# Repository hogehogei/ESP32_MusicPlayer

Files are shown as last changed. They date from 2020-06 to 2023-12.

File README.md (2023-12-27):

# ESP32 MusicPlayer sample

## 概要
- Bluetooth Classic 接続 / SDカードから　音声再生可能なミュージックプレーヤ
- 音声再生機能は VS1053b に丸投げ

## ビルド方法
ESP-IDF v4.4 にてビルド確認。 esp32 wroom 32 (無印esp32) での設定。<br>
以下menuconfig設定要
- Compiler options -> Optimization Level (-O2)
- Component config -> Bluetooth ->
    - Bluetooth controller -> Bluetooth controller mode (BR/EDR Only)
    - Bluetooth Host -> (Bluedroid - Dual-mode)
    - Bluedroid Options ->
        - [*] Classic Bluetooth
        - [*] A2DP
        - [*] SPP
- Component config -> ESP System Settings ->  Panic handler behaviour (Print registers and halt)
- Serial flasher config -> Flash size (4MB)
- Partition Table -> PartitionTable (custom partition table CSV)

最適化有効にしないとBluetoothパケットドロップするので最適化必須、CPUクロックは160MHzで動作。<br>
パーティションは partition.csv を参照する。

ビルドコマンド<br>
```
$ cd main
$ idf.py build
```

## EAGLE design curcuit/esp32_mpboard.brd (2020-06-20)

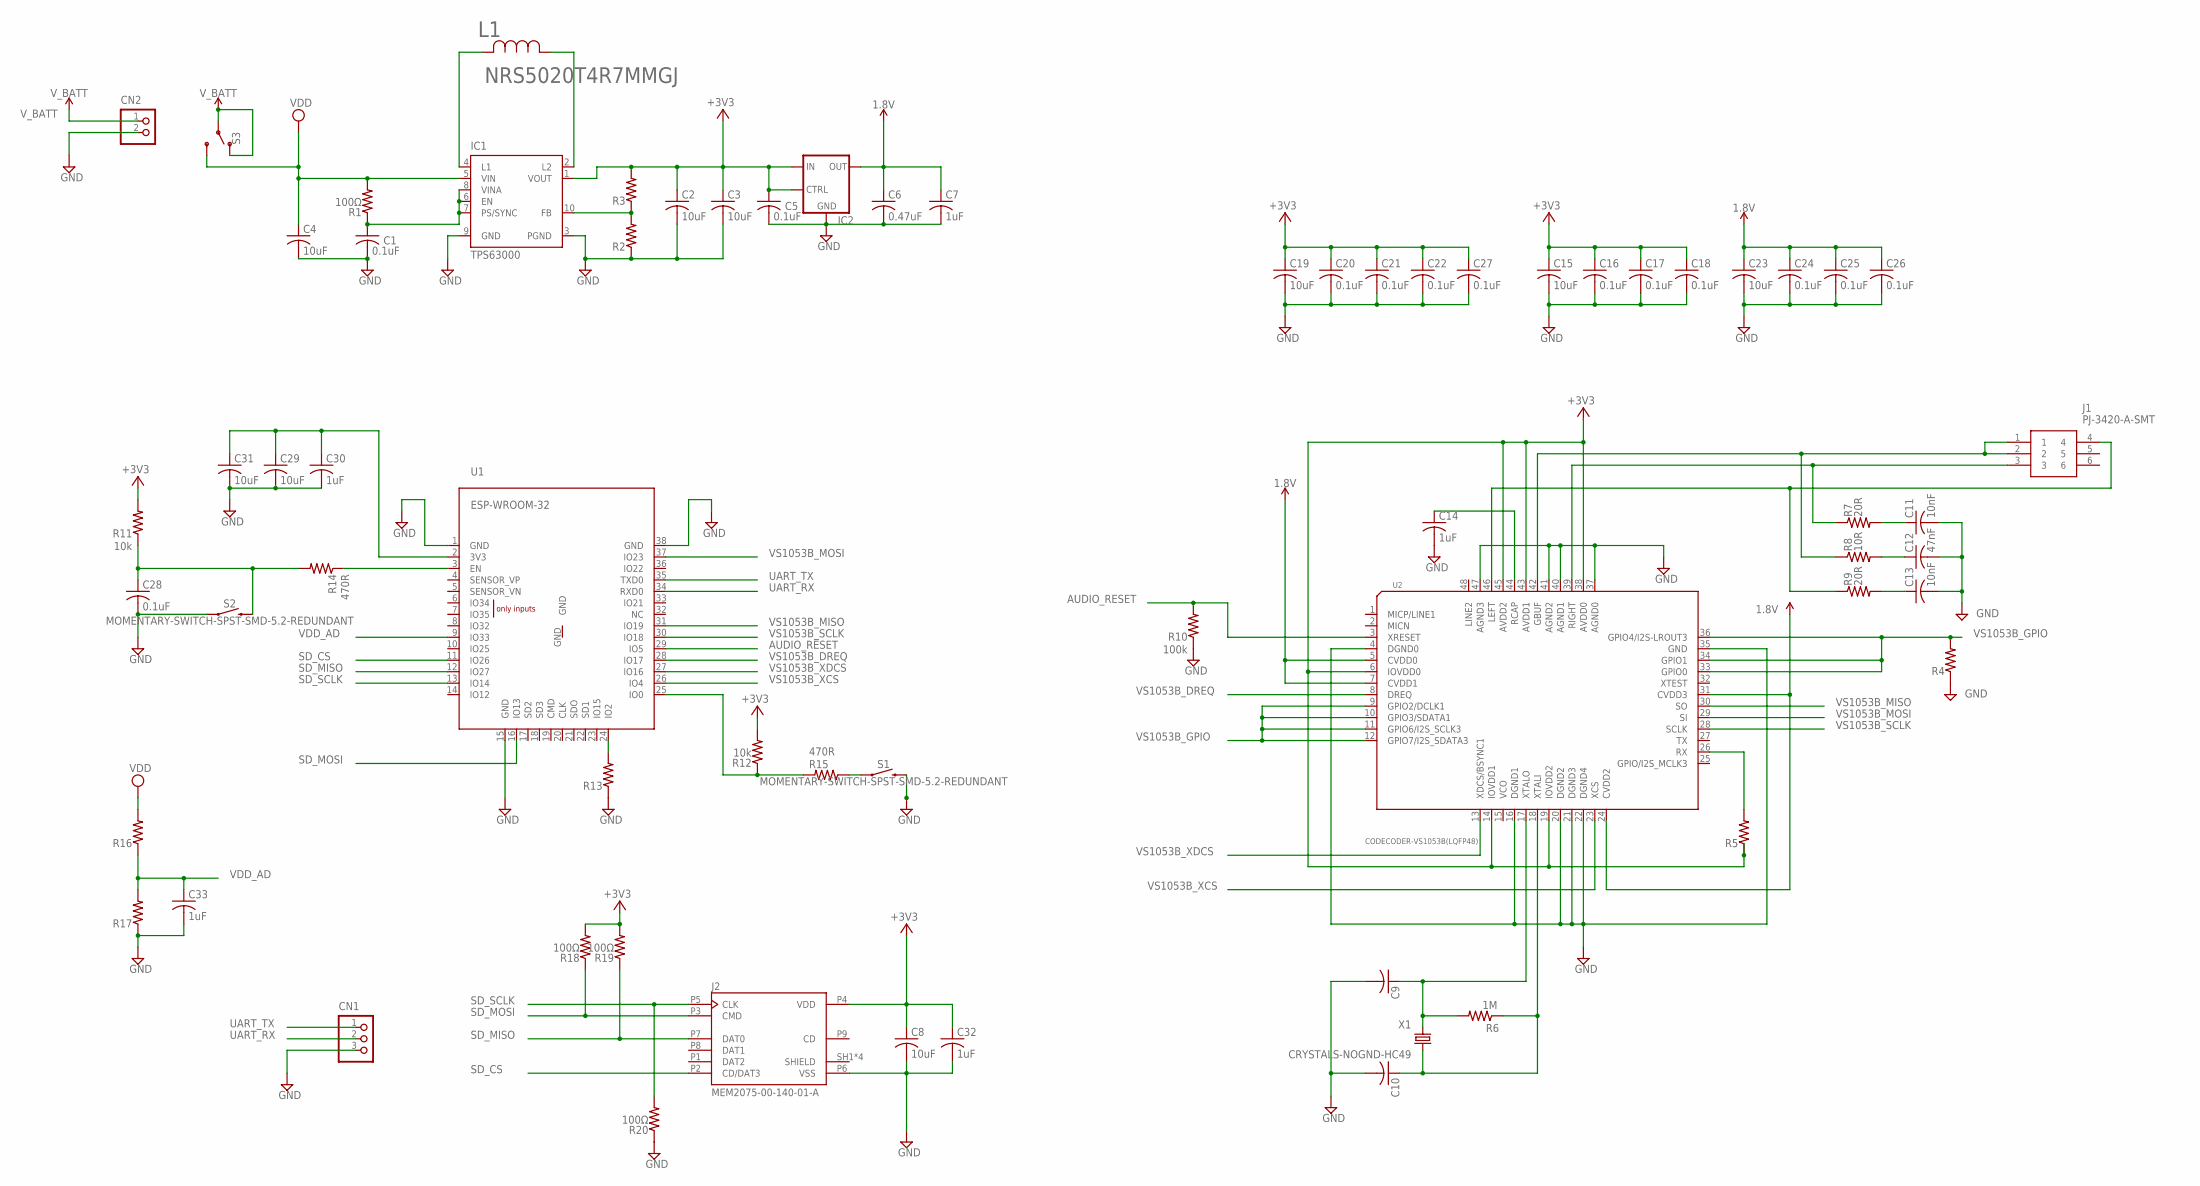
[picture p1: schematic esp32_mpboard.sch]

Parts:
C1, C5, C16, C17, C18, C20, C21, C22, C24, C25, C26, C27, C28: 0.1uF; C0603
C2, C3, C4, C8, C15, C19, C23, C29, C31: 10uF; C0805
C6: 0.47uF; C0603
C7, C14, C30, C32, C33: 1uF; C0603
C9, C10: C-USC0603; C0603
C11, C13: 10nF; C0603
C12: 47nF; C0603
CN1: B3B-XH-A
CN2: B2B-XH-A
IC1: TPS63000; DRC-S-PVSON-N10_MANUALSOLDER
IC2: NJM12888F1812DBV; SOT23-5
J1: PJ-3420-A-SMT; PJ3420ASMT
J2: MEM2075-00-140-01-A; GCT_MEM2075-00-140-01-A
L1: NRS5020T4R7MMGJ; IND_TAIYO_NRS5020
R1, R18, R19, R20: 100Ω; R0603
R2, R3, R4, R5, R13, R16, R17: R-US_R0603; R0603
R6: 1M; R0603
R7, R9: 20R; R0603
R8: 10R; R0603
R10: 100k; R0603
R11, R12: 10k; R0603
R14, R15: 470R; R0603
S1, S2: MOMENTARY-SWITCH-SPST-SMD-5.2-REDUNDANT; TACTILE_SWITCH_SMD_5.2MM
S3: SWITCH-SPDT-PTH-11.6X4.0MM; SWITCH_SPDT_PTH_11.6X4.0MM
U1: ESP-WROOM-32
U2: CODECODER-VS1053B(LQFP48); LQFP48-0.5-7X7MM
X1: CRYSTALS-NOGND-HC49; HC49

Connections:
1.8V: C6.1, C7.1, C23.1, C24.1, C25.1, C26.1, IC2.5 (OUT), U2.5 (CVDD0), U2.7 (CVDD1), U2.24 (CVDD2), U2.31 (CVDD3)
1.8V1: C9.1, R6.2, U2.17 (XTALO), X1.2
3V3: C2.1, C3.1, C5.1, C8.1, C15.1, C16.1, C17.1, C18.1, C19.1, C20.1, C21.1, C22.1, C27.1, C29.1, C30.1, C31.1, C32.1, IC1.1 (VOUT), IC2.1 (IN), IC2.3 (CONTROL), J2.P4 (VDD), R3.2, R5.1, R5.2, R12.2, R18.2, R19.2, U1.2 (3V3), U2.6 (IOVDD0), U2.14 (IOVDD1), U2.19 (IOVDD2), U2.26 (RX), U2.38 (AVDD0), U2.43 (AVDD1), U2.45 (AVDD2)
+3V3: R11.2
AUDIO_RESET: R10.2, U1.29 (IO5), U2.3 (XRESET)
GND: C1.2, C2.2, C3.2, C4.2, C5.2, C6.2, C7.2, C8.2, C9.2, C10.2, C11.2, C12.2, C13.2, C14.2, C15.2, C16.2, C17.2, C18.2, C19.2, C20.2, C21.2, C22.2, C23.2, C24.2, C25.2, C26.2, C27.2, C28.2, C29.2, C30.2, C31.2, C32.2, C33.2, CN1.3, CN2.2, IC1.3 (PGND), IC1.9 (GND), IC2.2 (GND), J2.P6 (VSS), R2.1, R4.1, R10.1, R13.1, R17.1, R20.1, S1.3 (2), S1.4 (2), S2.1, S2.2 (1), U1.1 (GND), U1.15 (GND), U1.38 (GND), U2.4 (DGND0), U2.16 (DGND1), U2.20 (DGND2), U2.21 (DGND3), U2.22 (DGND4), U2.35 (GND), U2.37 (AGND0), U2.40 (AGND1), U2.41 (AGND2), U2.47 (AGND3)
GND1: C10.1, R6.1, U2.18 (XTALI), X1.1
unnamed: IC1.4 (L1), L1.2
unnamed: IC1.2 (L2), L1.1
unnamed: C1.1, IC1.6 (EN), IC1.7 (PS/SYNC), IC1.8 (VINA), R1.1
unnamed: IC1.10 (FB), R2.2, R3.1
unnamed: J1.4, R9.1, U2.46 (LEFT)
unnamed: J1.1, J1.2, R8.1, U2.42 (GBUF)
unnamed: J1.3, R7.1, U2.39 (RIGHT)
unnamed: C12.1, R8.2
unnamed: C13.1, R9.2
unnamed: C11.1, R7.2
unnamed: R12.1, R15.2, U1.25 (IO0)
unnamed: C14.1, U2.44 (RCAP)
unnamed: C28.1, R11.1, R14.2, S2.3 (2), S2.4 (2)
unnamed: R13.2, U1.24 (IO2)
unnamed: R14.1, U1.3 (EN)
unnamed: R15.1, S1.1, S1.2 (1)
SD_CS: J2.P2 (CD/DAT3), U1.11 (IO26)
SD_MISO: J2.P7 (DAT0), R19.1, U1.12 (IO27)
SD_MOSI: J2.P3 (CMD), R18.1, U1.16 (IO13)
SD_SCLK: J2.P5 (CLK), R20.2, U1.13 (IO14)
SHIELD: J2.SH1 (SHIELD), J2.SH2 (SHIELD), J2.SH3 (SHIELD), J2.SH4 (SHIELD)
UART_RX: CN1.2, U1.34 (RXD0)
UART_TX: CN1.1, U1.35 (TXD0)
VCO: U2.15 (VCO)
VDD: C4.1, IC1.5 (VIN), R1.2, R16.2, S3.3 (S)
VDD_AD: C33.1, R16.1, R17.2, U1.9 (IO33)
VS1053B_DREQ: U1.28 (IO17), U2.8 (DREQ)
VS1053B_GPIO: R4.2, U2.9 (GPIO2/DCLK1), U2.10 (GPIO3/SDATA1), U2.11 (GPIO6/I2S_SCLK3), U2.12 (GPIO7/I2S_SDATA3), U2.33 (GPIO0), U2.34 (GPIO1), U2.36 (GPIO4/I2S-LROUT3)
VS1053B_MISO: U1.31 (IO19), U2.30 (SO)
VS1053B_MOSI: U1.37 (IO23), U2.29 (SI)
VS1053B_SCLK: U1.30 (IO18), U2.28 (SCLK)
VS1053B_XCS: U1.26 (IO4), U2.23 (XCS)
VS1053B_XDCS: U1.27 (IO16), U2.13 (XDCS/BSYNC1)
V_BATT: CN2.1, S3.1 (O), S3.2

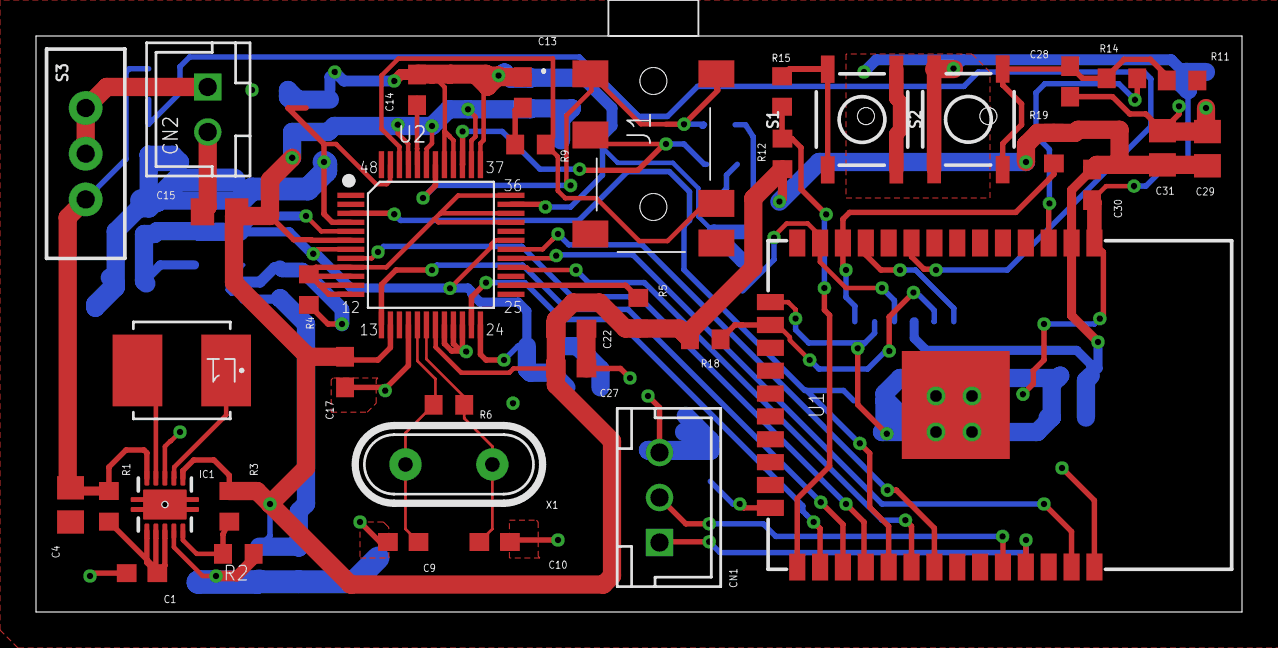
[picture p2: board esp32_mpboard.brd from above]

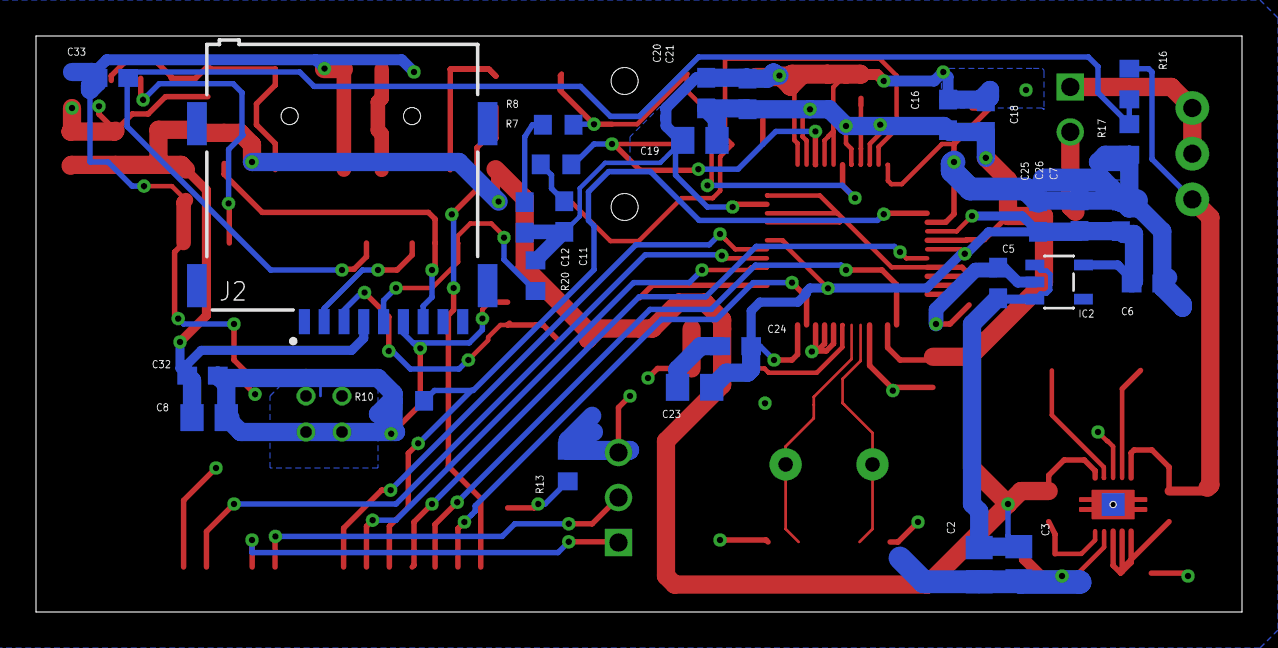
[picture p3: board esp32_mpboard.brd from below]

Board: 2 copper layers, 67.0 x 32.0 mm, 66 parts (28 on the bottom side), 39 nets.

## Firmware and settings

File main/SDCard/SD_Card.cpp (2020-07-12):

#include "SD_Card.hpp"

#include <limits>
#include <algorithm>

// esp-idf headers
#include "esp_log.h"

// FreeRTOS headers
#include <freertos/FreeRTOS.h>
#include <freertos/task.h>

// SDCard Command Set
static constexpr uint8_t sk_CMD0        = (0x40 + 0);
static constexpr uint8_t sk_CMD1        = (0x40 + 1);
static constexpr uint8_t sk_CMD8        = (0x40 + 8);
static constexpr uint8_t sk_CMD9        = (0x40 + 9);
static constexpr uint8_t sk_CMD16       = (0x40 + 16);
static constexpr uint8_t sk_CMD17       = (0x40 + 17);
static constexpr uint8_t sk_CMD25       = (0x40 + 25);
static constexpr uint8_t sk_ACMD41      = (0xC0 + 41);
static constexpr uint8_t sk_CMD55       = (0x40 + 55);
static constexpr uint8_t sk_CMD58       = (0x40 + 58);
static constexpr uint8_t sk_ACMD_Mask   = (0x80);                   //! ACMDマスク値 コマンドにANDして1の場合はACMD
static constexpr uint32_t sk_ACMD41_HCS = (1UL << 30);
static constexpr uint32_t sk_ACMD58_CCS = (0x40);

// SDCard Command Response
static constexpr uint8_t sk_CMD_RES_InIdleState = (1 << 0);
static constexpr uint8_t sk_CMD_RES_OK  = 0x00;

// SDCard Data Token
static constexpr uint8_t sk_ErrorTokenMask     = 0x01;              //! エラートークンマスク
static constexpr uint8_t sk_DataToken_Read     = 0xFE;              //! CMD17 データトークン
static constexpr uint8_t sk_DataToken_CMD25    = 0xFC;              //! CMD25 データトークン
static constexpr uint8_t sk_StopTransToken_CMD25 = 0xFD;            //! CMD25 StopTrans

// SDCard Data Response
static constexpr uint8_t sk_DATA_RES_OK_Mask = 0x1F;
static constexpr uint8_t sk_DATA_RES_OK      = 0x05;

// SDCard Type
static constexpr uint8_t sk_SDC_Type_None   = 0;                    //! SDカードタイプ無し。初期化に失敗した時とかはこれ
static constexpr uint8_t sk_SDC_Type_SD1    = (1 << 0);             //! SDカード = SDv1
static constexpr uint8_t sk_SDC_Type_SD2    = (1 << 1);             //! SDカード = SDv2
static constexpr uint8_t sk_SDC_Type_MMC    = (1 << 2);             //! SDカード = MMC
static constexpr uint8_t sk_SDC_Block       = (1 << 3);             //! ブロックアクセス     1の場合はコマンドのアドレス指定はsector単位を用いる。
                                                                    //!                     0の場合はコマンドのアドレス指定はbyte単位。

// read() / write() 関数の引数 sector を byte に変換するときに
// sector がとりうることのできる最大値
static constexpr uint32_t k_MaxSector_ByteAccess = (std::numeric_limits<uint32_t>::max() / SD_Card::sk_SectorSize);

// SDカードアクセス時間指定

static constexpr uint8_t sk_SDC_InitDelay_ms    = 100;              //! SDC初期化ウェイト[ms]
static constexpr int sk_SDC_InitSCLK            = 10;               //! SDC初期化カウント[x8 clock]
static constexpr uint16_t sk_SDC_TimeOut_ms     = 1000;             //! SDCコマンドタイムアウト[ms]

static constexpr int sk_CMD_RespRetry           = 8192;             //! コマンドレスポンス読み出しリトライ回数
static constexpr int sk_DataPktReadWait         = 8192;             //! データパケットトークン読み出しリトライ回数
static constexpr int sk_WriteBusyCheckRetry     = 8192;             //! 書き込みビジーチェックリトライ回数

void showResp( const uint8_t resp );

SD_Card::Progress::Progress()
 :  addr( 0 ),
    remain_offset( 0 ),
    remain_sector( 0 ),
    remain_bytes_cursec( 0 ),
    remain_len( 0 )
{}

SD_Card::SD_Card()
 : m_SDC_Drv( nullptr ),
   m_W_Progress(),
   m_SDC_State( false ),
   m_IsWriteOpeProcessing( false ),
   m_CardType( 0 ),
   m_SectorCount( 0 )
{}

SD_Card::~SD_Card()
{}


bool SD_Card::Initialize( I_SDC_Drv_SPI* driver )
{
    // 初期化済み、かつ正常動作中なら何もしない。
    if( m_SDC_State == true ){
        return true;
    }

    // ドライバインターフェースを設定
    if( !driver ){
        m_SDC_State = false;
        return false;
    }
    m_SDC_Drv = driver;

    // SDカードドライバ初期化
    m_SDC_Drv->Initialize( sk_ClockSpeedHz_Initializing );
    sendInitializeClock();              // 初期化クロック送信
    m_CardType = initialize_Card();     // カード初期化
    // SPIの速度再設定
    m_SDC_Drv->Initialize( sk_ClockSpeedHz_AccessSD );
    
    if( m_CardType == sk_SDC_Type_None ){
        m_SDC_State = false;
    }
    else {
        // セクタサイズ読み込み
        readSectorSize();
        m_SDC_State = true;
    }

    // 初期化終了
    m_SDC_Drv->Release();

    printSDCardInfo();

    return m_SDC_State;
}

bool SD_Card::Read( uint8_t* dst, uint32_t sector, uint32_t offset, uint32_t len )
{
	// SDカード状態が不正ならエラー
	if( m_SDC_State == false ){
		return false;
	}

    if( len == 0 ){
        return true;
    }
    // 引数チェック
    // offset がセクタサイズ以上、もしくは
    // (offset + len) が32bitの取りえる値を超えていたら失敗
    if( dst == nullptr ||
        offset >= sk_SectorSize || 
        ((std::numeric_limits<uint32_t>::max() - offset) < len) ){
        return false;
    }
    // アクセス単位がbyte単位の場合に、上限値を超えたらエラー
    if( !(m_CardType & sk_SDC_Block) &&
        (sector > k_MaxSector_ByteAccess) ){
        return false;
    }

    // 進捗管理構造体
    Progress progress;
    bool result = readInitiate( &progress, sector, offset, len );

    // 3つの場合に分けて考える
    // step1: offset だけ先頭データを読み飛ばす
    // step2: 必要なデータをコピーする
    // step3: 必要なデータをすべて読み終わった後、最終セクタの余ったデータを読み飛ばす
    while( result &&
         (( progress.remain_len > 0 ) || ( progress.remain_bytes_cursec > 0 )) ){
#if 0
    	UART_Print( "Remain offset");
    	UART_HexPrint( (uint8_t* )&progress.remain_offset, 4 );
    	UART_Print( "Remain cursec");
    	UART_HexPrint( (uint8_t*)&progress.remain_bytes_cursec, 4 );
    	UART_Print( "Remain len");
    	UART_HexPrint( (uint8_t*)&progress.remain_len, 4 );
    	UART_Print( "Remain Sector");
    	UART_HexPrint( (uint8_t*)&progress.remain_sector, 4 );
#endif

        if( progress.remain_offset > 0 ){
            // step1
            ignoreRead( offset );
            progress.remain_bytes_cursec -= offset;
            progress.remain_offset = 0;
        }
        else if( progress.remain_len > 0 ){
            // step2
            uint32_t size = std::min( progress.remain_len, progress.remain_bytes_cursec );
            result = m_SDC_Drv->recv( dst, size );
            dst += size;
            progress.remain_len -= size;
            progress.remain_bytes_cursec -= size;
        }
        else if( progress.remain_bytes_cursec > 0 ){
            // step3 
            ignoreRead( progress.remain_bytes_cursec );
            progress.remain_bytes_cursec = 0;
        }
        else {
            result = false;
        }

        if( progress.remain_bytes_cursec == 0 ){
            // CRCを読み飛ばす
            ignoreRead( 2 );
            // 残りのセクタを読む必要があるなら次のセクタを読む
            if( progress.remain_sector > 0 ){
                if( !nextSectorReadPreparation( &progress ) ){
                    result = false;
                    break;
                }
            }
        }
    }

    m_SDC_Drv->Release();
    m_SDC_State = result;

    return result;
}
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

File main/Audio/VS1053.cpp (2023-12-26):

#include "VS1053.hpp"

#include <cstdint>
#include <cstring>
#include "Timer.hpp"

// esp headers
#include "esp_log.h"

#include <esp32/rom/ets_sys.h>

static constexpr uint32_t sk_SPI_Send_Timeout = 1000;
static constexpr uint32_t sk_SPI_Recv_Timeout = 1000;
static constexpr uint32_t sk_Busy_Timeout = 1000;

VS1053_Drv_SPI VS1053_Drv_SPI::s_Driver;

VS1053_Drv_SPI::VS1053_Drv_SPI()
    : m_IsInitialized( false )
{}

VS1053_Drv_SPI::~VS1053_Drv_SPI()
{}

VS1053_Drv_SPI& VS1053_Drv_SPI::Instance()
{
    return s_Driver;
}

void VS1053_Drv_SPI::Initialize( uint32_t spi_freq )
{
    // SPI 初期化
    initialize_SPI( spi_freq );
    // CS pin 初期化
    initialize_CS( sk_CmdCS_IONum );
    CommandRelease();
	initialize_CS( sk_DataCS_IONum );
    DataRelease();
    // DREQ pin 初期化
    initialize_DReq( sk_DReq_IONum );
    // Audio Reset pin 初期化
    initialize_AudioReset( sk_AudioReset_IONum );

    m_IsInitialized = true;
}

void VS1053_Drv_SPI::ResetSPI( uint32_t spi_freq )
{
    initialize_SPI( spi_freq );
}

bool VS1053_Drv_SPI::CommandSelect()
{
    gpio_set_level( sk_CmdCS_IONum, 0 );
    return true;
}

void VS1053_Drv_SPI::CommandRelease()
{
    gpio_set_level( sk_CmdCS_IONum, 1 );
}

bool VS1053_Drv_SPI::DataSelect()
{
    gpio_set_level( sk_DataCS_IONum, 0 );
    return true;
}

void VS1053_Drv_SPI::DataRelease()
{
    gpio_set_level( sk_DataCS_IONum, 1 );
}

void VS1053_Drv_SPI::AssertReset()
{
    gpio_set_level( sk_AudioReset_IONum, 0 );
}

void VS1053_Drv_SPI::DeassertReset()
{
    gpio_set_level( sk_AudioReset_IONum, 1 );
}

bool VS1053_Drv_SPI::IsBusy() const
{
    return gpio_get_level( sk_DReq_IONum ) == 0;
}

bool VS1053_Drv_SPI::Send( const uint8_t* data, uint16_t len )
{
	static spi_transaction_t trans;
	esp_err_t ret;

	if( data == nullptr ){
		return false;
	}
	
	memset( &trans, 0, sizeof(spi_transaction_t) );
	trans.length    = len * 8;          // bit で指定
	trans.tx_buffer = data;				
	ret = spi_device_transmit( m_SPIHandle, &trans );

	return ret == ESP_OK;
}

bool VS1053_Drv_SPI::Recv( uint8_t* data, uint16_t len )
{
	static spi_transaction_t trans;

	if( data == nullptr ){
		return false;
	}

	// 受信時も 0xFF を送信するようにする。
	constexpr int k_TxBufSize = 16;
	uint8_t txbuf[k_TxBufSize] = {0xFF, 0xFF, 0xFF, 0xFF, 0xFF, 0xFF, 0xFF, 0xFF,
								  0xFF, 0xFF, 0xFF, 0xFF, 0xFF, 0xFF, 0xFF, 0xFF };
	uint32_t remain_len = len;
	uint8_t* dstp = data;

	memset( &trans, 0, sizeof(spi_transaction_t) );

	while( remain_len >= k_TxBufSize ){
		trans.length    = k_TxBufSize * 8;
		trans.rxlength  = k_TxBufSize * 8;
		trans.tx_buffer = txbuf;
		trans.rx_buffer = dstp;
		if( spi_device_transmit( m_SPIHandle, &trans ) != ESP_OK ){
			return false;
		}
		remain_len -= k_TxBufSize;
		dstp += k_TxBufSize;
	}
	if( remain_len > 0 ){
		trans.length    = remain_len * 8;
		trans.rxlength  = remain_len * 8;
		trans.tx_buffer = txbuf;
		trans.rx_buffer = dstp;
		if( spi_device_transmit( m_SPIHandle, &trans ) != ESP_OK ){
			return false;
		}
	}

    return true;
}
    
bool VS1053_Drv_SPI::SendRecv( const uint8_t* senddata, uint8_t* recvdata, uint16_t recvlen )
{
	static spi_transaction_t trans;

	if( senddata == nullptr || recvdata == nullptr ){
		return false;
	}

	memset( &trans, 0, sizeof(spi_transaction_t) );
	trans.length    = recvlen * 8;
	trans.rxlength  = recvlen * 8;
	trans.tx_buffer = senddata;
	trans.rx_buffer = recvdata;

    return spi_device_transmit( m_SPIHandle, &trans ) == ESP_OK;
}

void VS1053_Drv_SPI::initialize_SPI( uint32_t spi_freq )
{
    spi_bus_config_t buscfg = {};
    buscfg.miso_io_num = sk_MISO_IONum;
    buscfg.mosi_io_num = sk_MOSI_IONum;
    buscfg.sclk_io_num = sk_SCLK_IONum;
    buscfg.quadwp_io_num = -1;
    buscfg.quadhd_io_num = -1;
    buscfg.max_transfer_sz = sk_MaxTransferSize;

	spi_device_interface_config_t devcfg = {};
    devcfg.clock_speed_hz = spi_freq;             //Clock out 
    devcfg.mode = 0;                              //SPI mode 0
    devcfg.spics_io_num = -1;                     //CS pin
    devcfg.queue_size = 1;                        //We want to be able to queue 1 transactions at a time

    if( m_IsInitialized ){
        ESP_ERROR_CHECK( spi_bus_remove_device( m_SPIHandle ) );
        ESP_ERROR_CHECK( spi_bus_free( VSPI_HOST ) );
    }

	ESP_ERROR_CHECK( spi_bus_initialize( VSPI_HOST, &buscfg, sk_DMAChannel ) );
	ESP_ERROR_CHECK( spi_bus_add_device( VSPI_HOST, &devcfg, &m_SPIHandle ) );
}

void VS1053_Drv_SPI::initialize_CS( gpio_num_t ionum )
{
    gpio_config_t io_conf;
    //disable interrupt
    io_conf.intr_type = static_cast<gpio_int_type_t>(GPIO_PIN_INTR_DISABLE);
    //set as output mode
    io_conf.mode = GPIO_MODE_OUTPUT;
    //bit mask of the pins that you want to set
    io_conf.pin_bit_mask = (1ULL << ionum);
    //disable pull-down mode
    io_conf.pull_down_en = static_cast<gpio_pulldown_t>(0);
    //disable pull-up mode
    io_conf.pull_up_en = static_cast<gpio_pullup_t>(0);
    //configure GPIO with the given settings
    gpio_config(&io_conf);
}

void VS1053_Drv_SPI::initialize_DReq( gpio_num_t ionum )
{
    gpio_config_t io_conf;
    //disable interrupt
    io_conf.intr_type = static_cast<gpio_int_type_t>(GPIO_PIN_INTR_DISABLE);
    //set as output mode
    io_conf.mode = GPIO_MODE_INPUT;
    //bit mask of the pins that you want to set
    io_conf.pin_bit_mask = (1ULL << ionum);
    //disable pull-down mode
    io_conf.pull_down_en = static_cast<gpio_pulldown_t>(0);
    //disable pull-up mode
    io_conf.pull_up_en = static_cast<gpio_pullup_t>(0);
    //configure GPIO with the given settings
    gpio_config(&io_conf);
}

void VS1053_Drv_SPI::initialize_AudioReset( gpio_num_t ionum )
{
    gpio_config_t io_conf;
    //disable interrupt
    io_conf.intr_type = static_cast<gpio_int_type_t>(GPIO_PIN_INTR_DISABLE);
    //set as output mode
    io_conf.mode = GPIO_MODE_OUTPUT;
    //bit mask of the pins that you want to set
    io_conf.pin_bit_mask = (1ULL << ionum);
    //disable pull-down mode
    io_conf.pull_down_en = static_cast<gpio_pulldown_t>(0);
    //disable pull-up mode
    io_conf.pull_up_en = static_cast<gpio_pullup_t>(0);
    //configure GPIO with the given settings
    gpio_config(&io_conf);
}





VS1053_Drv::VS1053_Drv()
    : m_IsInitialized( false )
{}

VS1053_Drv::~VS1053_Drv()
{}

VS1053_Drv& VS1053_Drv::Instance()
{
    static VS1053_Drv s_Instance;
    return s_Instance;
}
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

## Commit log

2020-01-12 ・Initial Commit
2020-02-03 ・bluetooth audio 受信部など実装 まだ動かない
2020-02-04 ・Bluetooth 初期化コードを修正。 ・menuconfig で Bluetooth のコンポーネント設定を変更。 ・タスクループにDelayを追加。
2020-02-24 ・ Bluetooth で音楽再生できるようになった
2020-02-27 ・回路図作成中
    [esp32_mpboard.sch]
2020-06-20 ・SDカード読み込み処理を追加 ・ガーバーファイルを更新
    [esp32_mpboard.brd, esp32_mpboard.sch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]
2020-07-12 ・ひとまず完成 SDカードとBluetoothから音楽再生可能になる
2021-08-13 ・BLE起動時のbrownout対策に PHY の出力低減設定追加 ・パーティション設定をカスタム仕様にした
    [partitions.csv]
2021-08-13 ・README変更
2021-08-13 ・README修正
2023-12-26 ESP-IDF v4.4 対応
    [partitions.csv]
2023-12-26 SDカード/BT初期化失敗時に音楽再生タスクを停止する処理を追加
2023-12-26 プレーや種別切り替え時に、VS1053bもハードウェアリセットする
2023-12-26 ドライバ初期化順修正
2023-12-27 abort()時に自動再起動しないようにする
2023-12-28 入力電圧検出抵抗を修正し5V入力まで対応

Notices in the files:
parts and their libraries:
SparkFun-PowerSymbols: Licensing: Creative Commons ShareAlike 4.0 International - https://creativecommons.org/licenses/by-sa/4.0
